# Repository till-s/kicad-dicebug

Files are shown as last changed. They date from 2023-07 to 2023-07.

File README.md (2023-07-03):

# The DiceBug

*by Till Straumann, 2023*

## Introduction

This is a simple electronics project that I have created to
teach kids how electronic circuits are "built" -- in a physical
sense. They don't have to understand how it works (6 year olds
have assembled the bug) but just have fun placing the small
components on the board, watching the solder melt in a toaster
oven and walk away with the finished product.

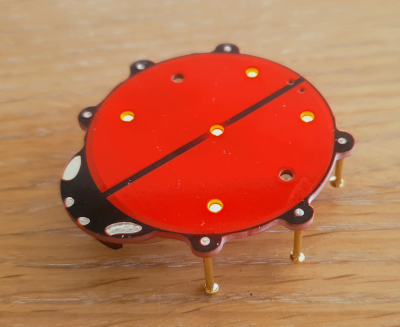
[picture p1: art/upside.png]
Upside View
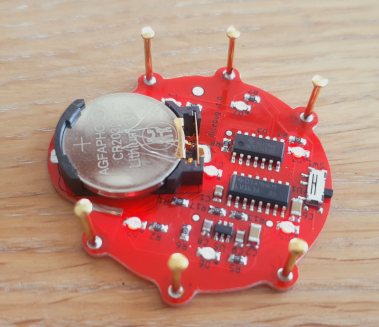
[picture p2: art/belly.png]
Belly View
 

The cute bug features a motion sensor and operates as an "electronic
dice" cycling throught the familiar patterns of pips we know from
traditional dice. The cycling is randomly triggered by hand motion
and happens too fast to control the outcome. When the hand is withdrawn
the bug will show a random facet.

The bug's preferred meal is a CR2032 lithium battery. A small power-switch
is located at the tail end of the animal.

Occasionally, the motion sensor may have to recalibrate itself
(the dice seems to be "stuck" when that happens). Just leave it alone
for several seconds (no touching) and it will come back to life.

Since the battery is exposed don't store the or operate the device
in a conducting bag or box.

## Warning

*Keep (any type of) batteries away from small children. Swallowing
batteries can be life-threatening!*

## Assembly Instructions

### Prerequisites

#### PCB

You need to have the PCB manufactured. There are many companies (mostly
in China) who do this cheaply. I found, however, that most manufacturers
would not offer the red solder mask combined with black ink (silkscreen)
that I liked. Eventually, I came across [elecrow](https://www.elecrow.com)
who would make the PCBs the way I wanted them (slightly more
expensive "premium service").

Make sure to also order a couple of stainless steel stencils
(more than one if you work with groups of kids). PCB manufacturers often
also offer stencils and you save on shipping cost when ordering from a
single source...

#### Parts

The parts can be obtained from the usual electronics distributors
(DigiKey, Mouser, Farnell, ...). These sources also sell solder
paste; I had good results with lead-free low-temperature
paste, Chipquik TS391LT50, which melts around 138degC.

Brass-plated nails, 1.2mm (dia) x 12mm (length), which I found at a DIY shop
make nice legs.

For the actual soldering you'll need a cheap toster oven or a hotplate,
YMMV. There are many instructions available on the internet.

#### IQS211 Capacitive Sensor Programming

Azoteq's IQS211 is very versatile and ideal for this kind of application.
I have regularly found it at Mouser; DigiKey sometimes don't have them.

Note that you need to configure ("burn") the IQS211's OTP options prior
to using it in your application. Unfortunately, this means that you need
the Azoteq CT210 Programmer (also available from distributors) and a
programming socket (e.g., [here](https://github.com/till-s/kicad-sot23-prog.git)).

The configuration value is stated in the schematics.

### Assembly

Nothing special here; I have a bunch of tweezers that I lend to the
kids so that they can work in parallel. Usually a kid's eyesight is
good enough to see the 805 parts perfectly. Adults may need glasses.

Spend some time on the internet if you have never done this; there
are many resources available that teach how to harness SMT.

Obvously, you only install the battery into the holder after soldering
the board.

#### Feet

After assembling and soldering/toasting the board I use a small hammer
and carefully hit the small nails just enough so that they hold on
in the mounting holes. Turn the bug on its feet to verify that it stands
nicely tweaking the feet if necessary. Eventually, you use a conventional
soldering iron and (lead-free) solder to fix the feet permanently.

### Good luck!

### License

This project is licensed under the
[OHL-S open-hardware license](https://ohwr.org/project/cernohl/wikis/Documents/CERN-OHL-version-2);
the artwork was created by my kid Adam and is licensed under
[CC-BY-NC-ND](http://creativecommons.org/licenses/by-nc-nd/4.0/).

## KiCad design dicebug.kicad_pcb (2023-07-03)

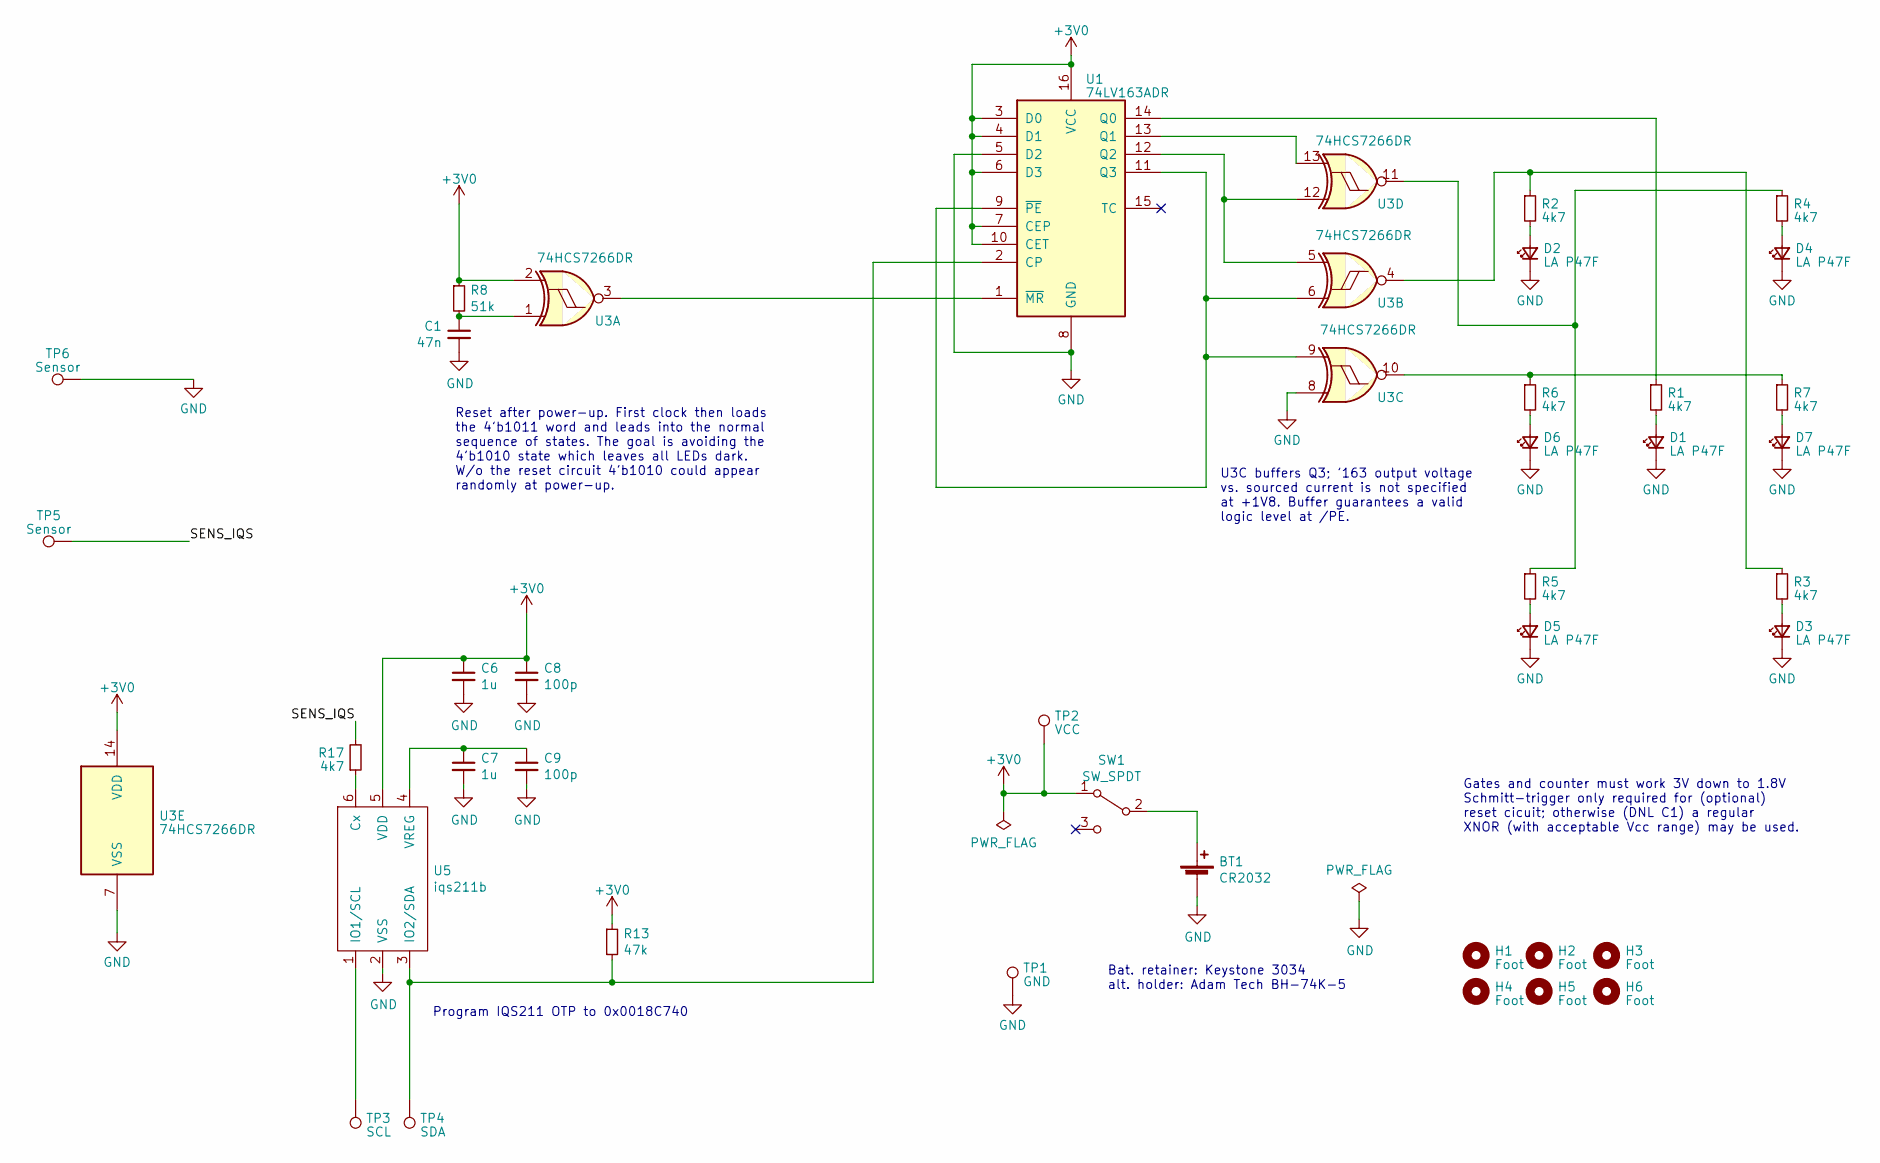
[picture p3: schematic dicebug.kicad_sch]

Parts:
BT1: CR2032; bh-3034-74-combined; Part 3034
C1: 47n; C_0805_2012Metric; Part CL21B473KCFNNNF
C6, C7: 1u; C_1206_3216Metric; Part C3216X5R1H105M160AA
C8, C9: 100p; C_0805_2012Metric; Part C0603C101J5GACTU
D1, D2, D3, D4, D5, D6, D7: LA P47F; PointLED_reverse_mount_bigger_pads; Part LA P47F-V2BB-24-3A4B-Z
H1, H2, H3, H4, H5, H6: Foot; foot
R1, R2, R3, R4, R5, R6, R7, R17: 4k7; R_0805_2012Metric
R8: 51k; R_0805_2012Metric
R13: 47k; R_0805_2012Metric
SW1: SW_SPDT; 450404015514; Part 450404015514
TP1: GND; TestPoint_Pad_D2.0mm
TP2: VCC; TestPoint_Pad_D1.0mm
TP3: SCL; TestPoint_Pad_D1.0mm
TP4: SDA; TestPoint_Pad_D1.0mm
TP5, TP6: Sensor; tp_end
U1: 74LV163ADR; SOIC-16_3.9x9.9mm_P1.27mm; Part 74LV163ADR
U3: 74HCS7266DR; SOIC-14_3.9x8.7mm_P1.27mm; Part 74HCS7266DR
U5: iqs211b; SOT-23-6; Part IQS211B

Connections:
+3V0: C6.1, C8.1, R8.1, R13.1, SW1.1 (A), TP2.1, U1.3 (D0), U1.4 (D1), U1.6 (D3), U1.7 (CEP), U1.10 (CET), U1.16 (VCC), U3.2, U3.14 (VDD), U5.5 (VDD)
/SENS_IQS: R17.2, TP5.1
GND: BT1.2 (-), C1.2, C6.2, C7.2, C8.2, C9.2, D1.1 (K), D2.1 (K), D3.1 (K), D4.1 (K), D5.1 (K), D6.1 (K), D7.1 (K), TP1.1, TP6.1, U1.5 (D2), U1.8 (GND), U3.7 (VSS), U3.8, U5.2 (VSS)
unnamed: BT1.1 (+), SW1.2 (B)
unnamed: C1.1, R8.2, U3.1
unnamed: D1.2 (A), R1.2
unnamed: D2.2 (A), R2.2
unnamed: D3.2 (A), R3.2
unnamed: D4.2 (A), R4.2
unnamed: D5.2 (A), R5.2
unnamed: D6.2 (A), R6.2
unnamed: D7.2 (A), R7.2
unnamed: R2.1, R3.1, U3.4
unnamed: R4.1, R5.1, U3.11
unnamed: R6.1, R7.1, U3.10
unnamed: R13.2, TP4.1, U1.2 (CP), U5.3 (IO2/SDA)
unnamed: R1.1, U1.14 (Q0)
unnamed: U1.13 (Q1), U3.13
unnamed: U1.12 (Q2), U3.5, U3.12
unnamed: U1.9 (~PE), U1.11 (Q3), U3.6, U3.9
unnamed: U1.1 (~MR), U3.3
unnamed: R17.1, U5.6 (Cx)
unnamed: TP3.1, U5.1 (IO1/SCL)
unnamed: C7.1, C9.1, U5.4 (VREG)

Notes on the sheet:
Bat. retainer: Keystone 3034 alt. holder: Adam Tech BH-74K-5
Program IQS211 OTP to 0x0018C740
Reset after power-up. First clock then loads the 4'b1011 word and leads into the normal sequence of states. The goal is avoiding the 4'b1010 state which leaves all LEDs dark. W/o the reset circuit 4'b1010 could appear randomly at power-up.
Gates and counter must work 3V down to 1.8V Schmitt-trigger only required for (optional) reset cicuit; otherwise (DNL C1) a regular XNOR (with acceptable Vcc range) may be used.
U3C buffers Q3; '163 output voltage vs. sourced current is not specified at +1V8. Buffer guarantees a valid logic level at /PE.

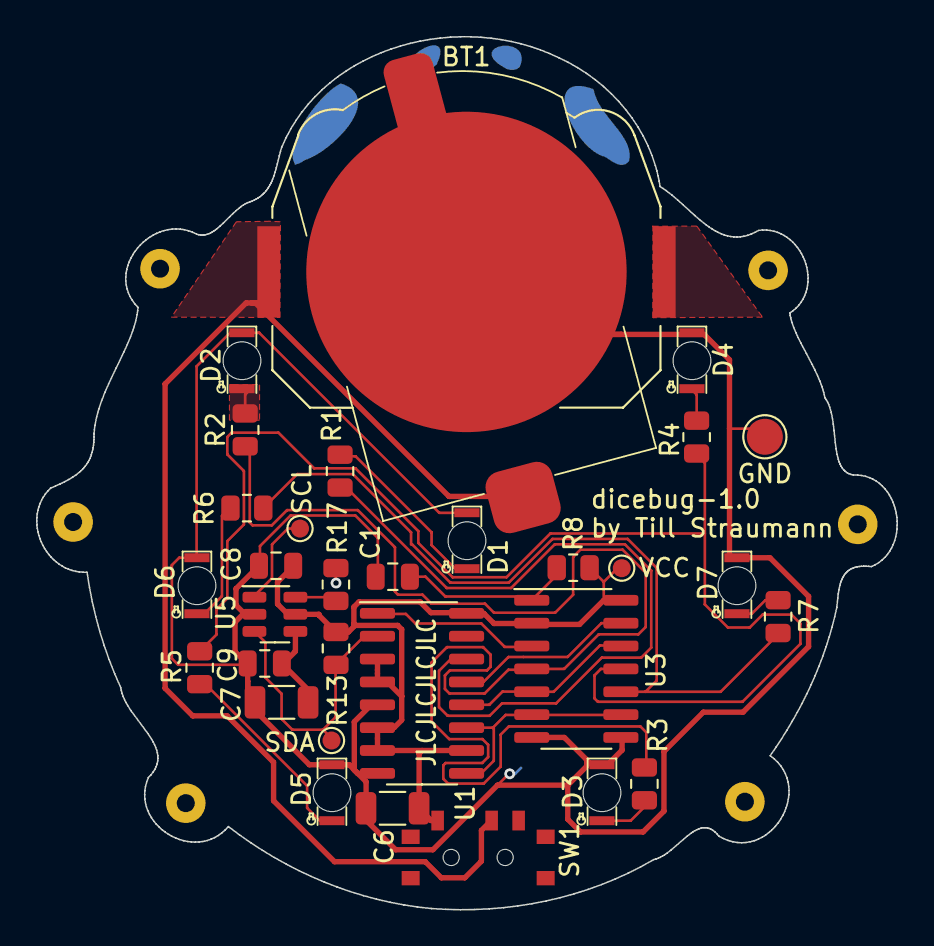
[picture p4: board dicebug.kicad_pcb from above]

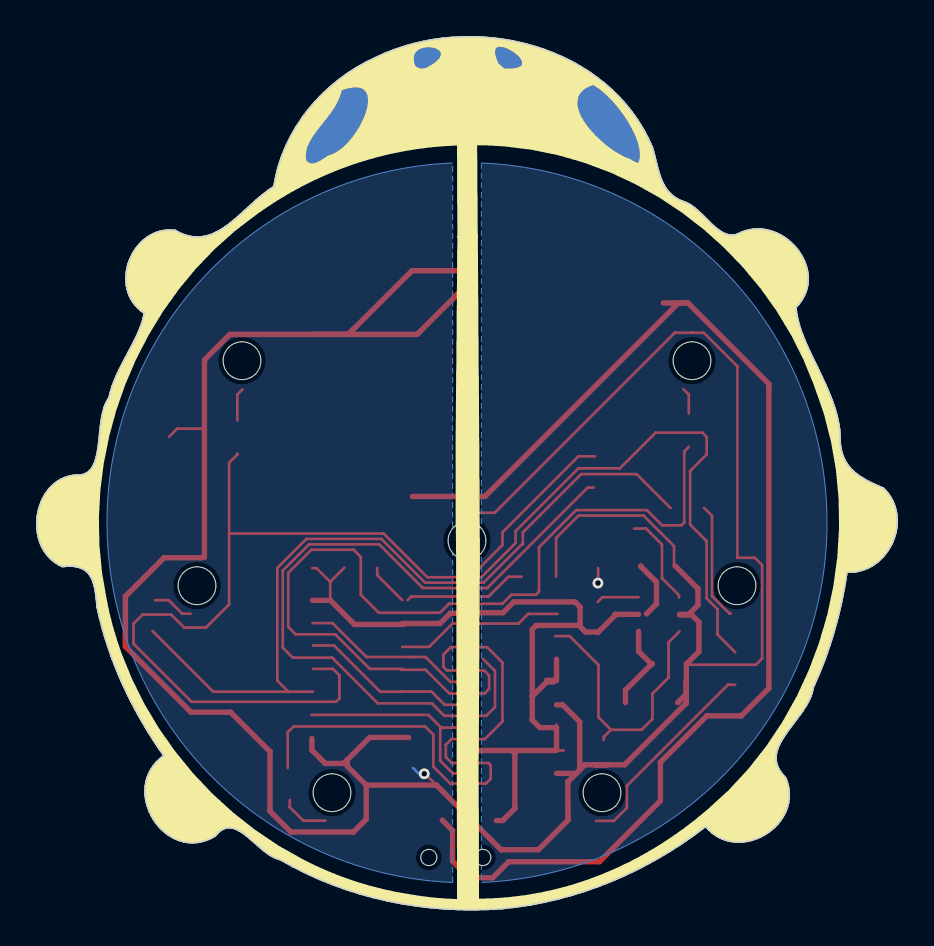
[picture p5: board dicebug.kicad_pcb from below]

Board: 2 copper layers, 47.8 x 48.5 mm, 39 parts (2 on the bottom side), 24 nets.

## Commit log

2023-05-07 added files to git
    [dicebug.kicad_pcb, dicebug.kicad_sch]
2023-05-07 pcb: gerber settings
    [dicebug.kicad_pcb]
2023-05-07 removed 1 directory level
    [dicebug.kicad_pcb, dicebug.kicad_sch]
2023-05-09 almost finalized with individual LED resistors, though
    [dicebug.kicad_pcb, dicebug.kicad_sch]
2023-05-09 improved layout (feet area clear)
    [dicebug.kicad_pcb, dicebug.kicad_sch]
2023-05-16 WIP: integrating artwork
    [dicebug.kicad_pcb, dicebug.kicad_sch]
2023-05-16 mostly done...
    [dicebug.kicad_pcb, dicebug.kicad_sch]
2023-05-30 updated part values, numbers/id and manufacturers; added comments
    [dicebug.kicad_pcb, dicebug.kicad_sch]
2023-05-30 added missing local footprints; moved art to subdir
2023-05-30 Added title + author info to schematic
    [dicebug.kicad_sch]
2023-05-31 Fixed fab layer
    [dicebug.kicad_pcb, dicebug.kicad_sch]
2023-07-03 schematic: added license info
    [dicebug.kicad_sch]
2023-07-03 PCB: removed feet from paste layer.
    [dicebug.kicad_pcb, dicebug.kicad_sch]
2023-07-03 Changed second resistor from 47k to 51k
    The reason for using 51k is simply for easier identification.
    If the resistors have their values printed on the package
    you can distinguish 4k7 vs 51k simply by looking for a 4 vs 5...
    [dicebug.kicad_sch]

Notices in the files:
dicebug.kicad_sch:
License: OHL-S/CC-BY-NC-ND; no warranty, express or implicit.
